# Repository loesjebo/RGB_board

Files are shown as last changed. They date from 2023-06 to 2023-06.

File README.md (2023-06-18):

# RGB_board

Simple 3V board design with tact switch and potmeter to control a RGB LED for a workshop I developed at ArtechLAB Amsterdam for Museum M in Almere. 

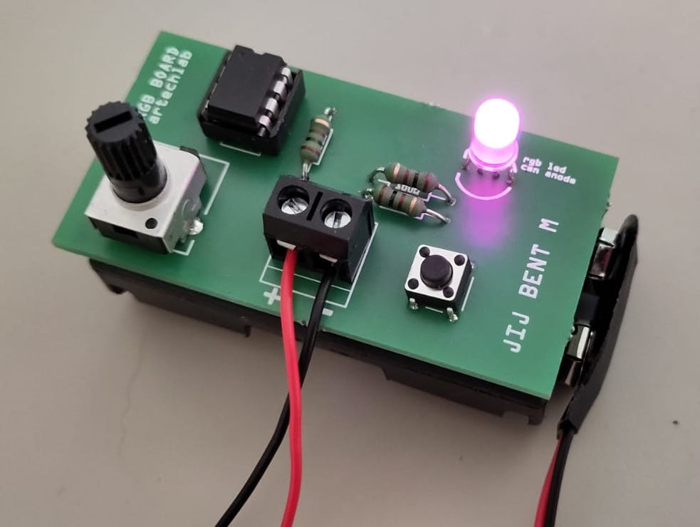
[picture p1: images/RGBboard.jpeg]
bottom of the board
  

## Description

This board runs on 3V and is also the size of a 2x AA battery pack. It features an attiny85 microcontroller, a potentiometer, a tact switch and a common anode RGB LED. 

With the tact switch different color modes can be selected (red, green or blue). Within each color mode, the intensity can be modified by turning the potentiometer knob. 

It was designed for a high school workshop to engage teenagers in immersive designs by playing with lighting and paper structures. 

## Bill of materials

### Tools

**Arduino IDE with following installed**
 
* ATtiny microcontrollers boards (via board manager, see below) 
* The arduino sketch under "files" in this repository [RGB_attiny_pot_switch_3V.ino](./files/RGB_attiny_pot_switch_3V/RGB_attiny_pot_switch_3V.ino) 
* Sparkfun tiny AVR programmer [€22 via robotshop](https://eu.robotshop.com/products/tiny-avr-usb-programmer).

You could also program the ATtiny with an Arduino UNO microcontroller, a breadboard, and a bunch of dupont jumpers. [See this instructable](https://srituhobby.com/how-to-program-attiny85-with-arduino-uno-step-by-step/)

**Hand tools**

* Small flathead screwdriver to connect battery leads to screw terminal
* Soldering iron and solder
* Multimeter

### Components per board

* [Solderable screw terminal (2 ports)](https://www.reichelt.nl/nl/nl/loetbare-schraubklemme-2-pol-rm-5-mm-90--ctb5202-2-p292669.html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)
* [3x 100 ohm resistors](https://www.reichelt.nl/nl/nl/koolstoffilmweerstand-1-4w-5-100-ohm-1-4w-100-p1336.html?&nbc=1)
* [Attiny85 chip (DIP)](https://www.reichelt.nl/nl/nl/8-bit-attiny-avr-risc-microcontroller-8-kb-20-mhz-dip-8-attiny-85-20-pu-p69299.html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)
* [9V battery clip](https://www.reichelt.nl/nl/nl/batterijclip-voor-9-volt-blok-verticaal-clip-9v-p6665.html?&nbc=1)
* [Battery holder 2x AA mignon batteries with connector that matches the battery clip](https://www.reichelt.nl/nl/nl/houder-voor-2-mignoncellen-aa-drukknop-halter-2xum3-dk-p8438.html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)
* [RGB LED (common anode)](https://opencircuit.nl/product/rgb-5mm-diffuse-led-common-anode)
* [Potentiometer ](https://opencircuit.nl/product/10k-rv09-verticale-potentiometer)
* [Tact switch 6 mm](https://opencircuit.nl/product/tactiele-button-6x6x5mm)
* The printed circuit board (PCB) (this design can be ordered [here](https://aisler.net/p/CUOELNLM))
* [2x AA batteries](https://www.reichelt.nl/nl/nl/set-van-40-batterijen-alkaline-mignon-ansmann-ans-al40-pack-p104406.html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)

## Board design

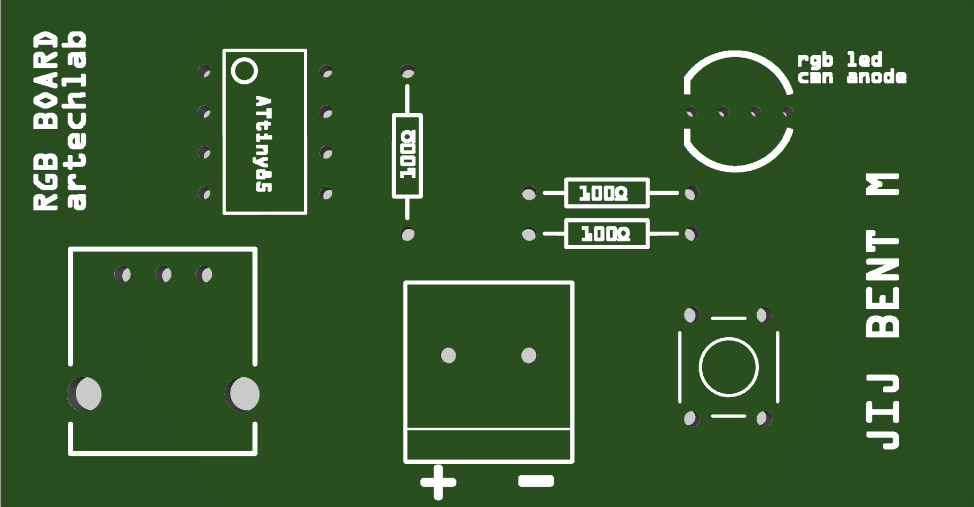
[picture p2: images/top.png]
top of the board
  

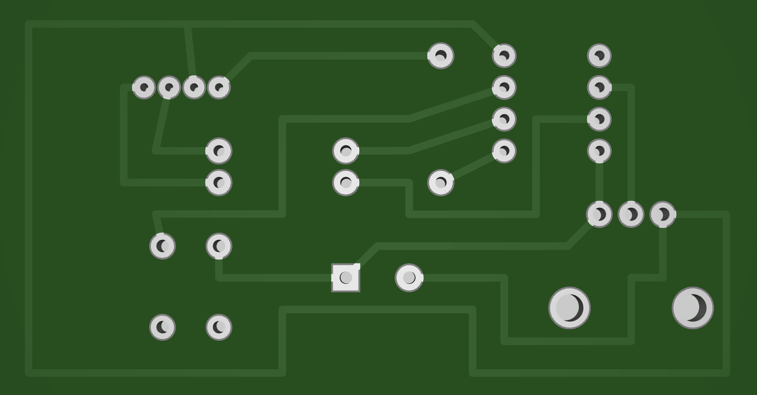
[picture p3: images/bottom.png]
bottom of the board
  

## Programming the ATtiny85 chip

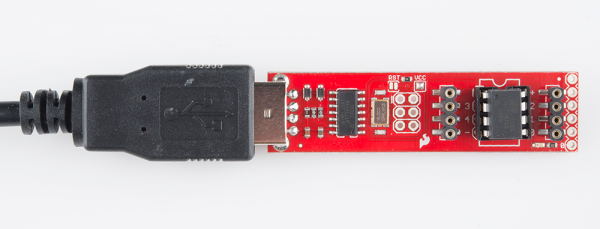
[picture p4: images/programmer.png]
sparkfun tiny avr programmer
  

### Install the [Arduino IDE](https://www.arduino.cc/en/software) software

* Download and open the sketch: [RGB_attiny_pot_switch_3V.ino](./files/RGB_attiny_pot_switch_3V/RGB_attiny_pot_switch_3V.ino)

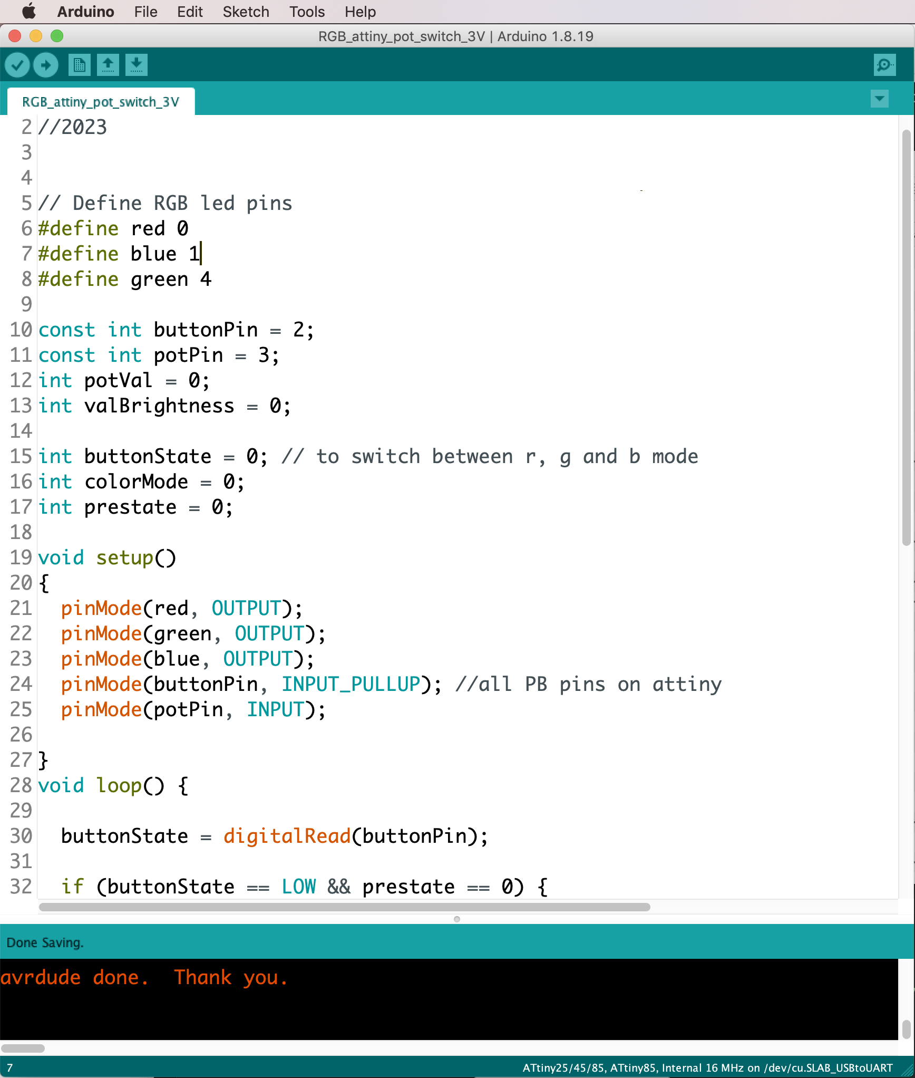
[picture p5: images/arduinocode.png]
	 

### Install the ATtiny board files 

Find via the menu bar *> Tools > Board > Board Manager...*  and search for **"attiny"**. Then click **"install"**.

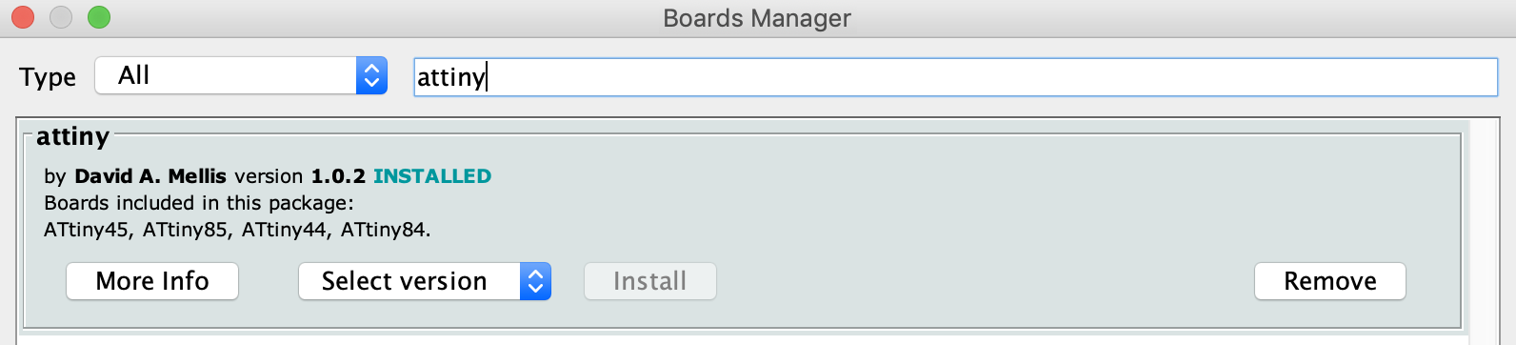
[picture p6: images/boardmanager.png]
 

* Restart the Arduino IDE software and reopen it
* Now you should find **ATtiny microcontrollers** under *Tools > Board*. 

### Selecting the board and programmer

Select **ATtiny25/45/85**

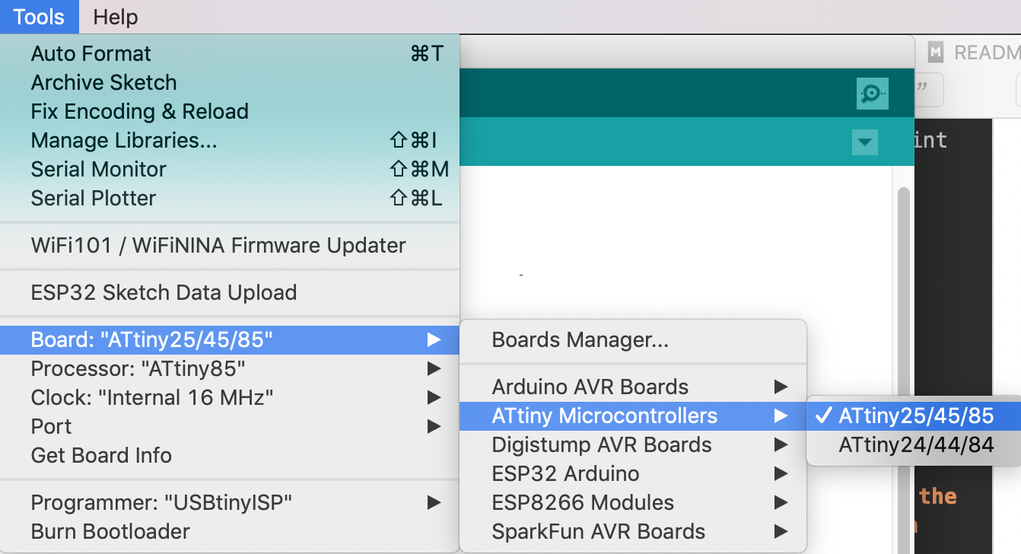
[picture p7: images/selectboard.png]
 

Select the right board settings as in the screenshot

* Board = ATtiny25/45/85
* Processor = ATtiny85
* Clock = Internal 1MHz
* Programmer = USBtinyISP

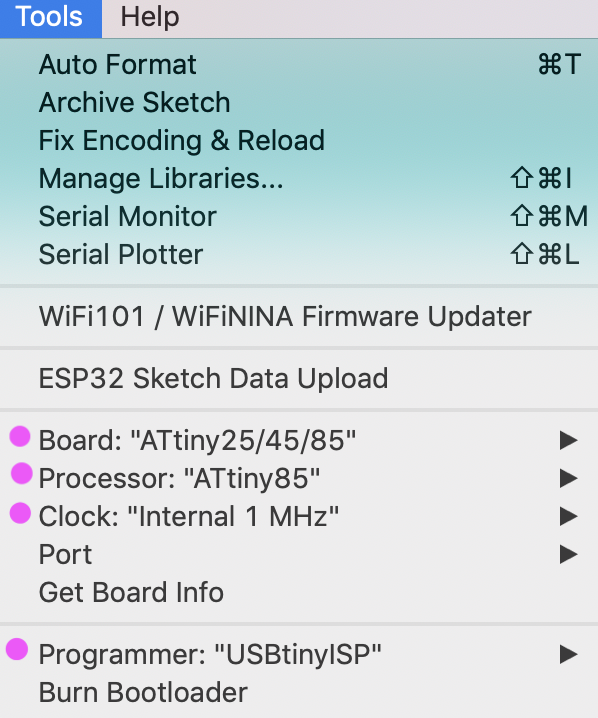
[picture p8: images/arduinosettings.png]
 

### Upload the code via the programmer

* Carefully plug the ATtiny85 chip into the socket on the board. 
	* Make sure the mark on the chip is in the right direction!

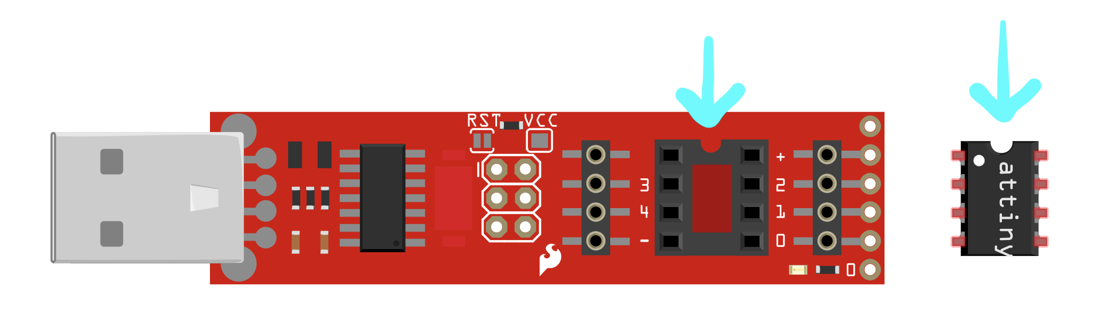
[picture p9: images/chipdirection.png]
	 
	
* Plug the stick into your computer's USB port and select >> **Sketch** >> **Upload** from the menu. The monitor should say "avrdude done. Thank you"

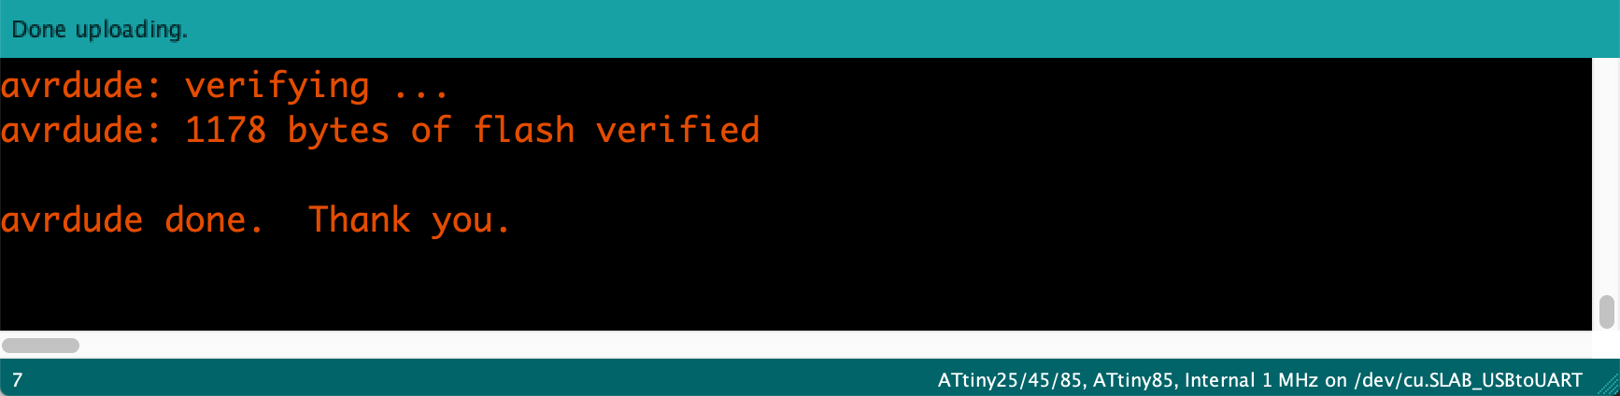
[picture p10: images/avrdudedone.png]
	 

* The Attiny chip has now been programmed

## Assembly

### 1. Program the ATtiny chip before sholdering

See above

### 2. Stuffing the board

Solder all parts to the boards following this diagram. Note the orientation of the following: 

* the long leg on the RGB is the common anode and goes into the second hole of the led footprint
* note the notch on the attiny85 chip, it marks the orientation and should point in the same direction of the little circle in the silkscreen of the footprint
* glue or tie the battery pack to the board, screw the wires into the screw terminal. The red lead goes to the + and the black lead goes to the -. 

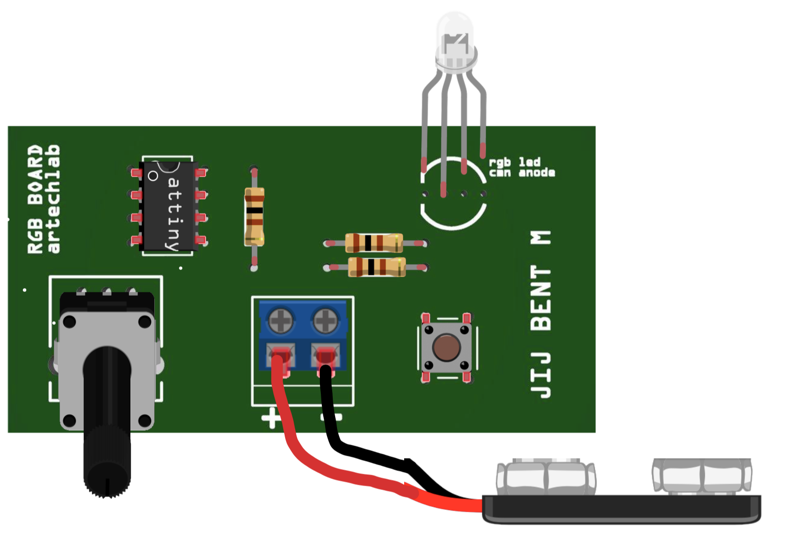
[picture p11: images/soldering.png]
  

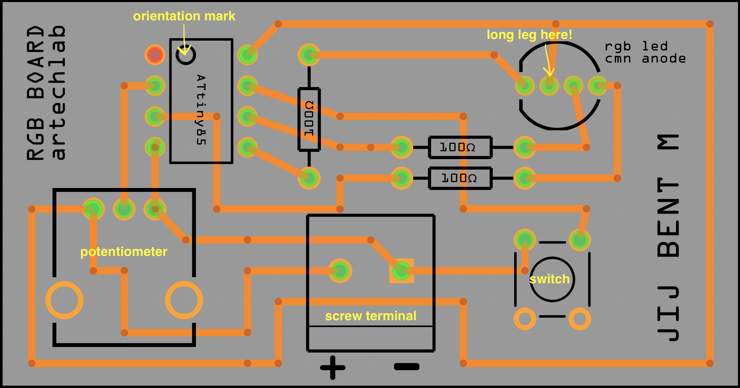
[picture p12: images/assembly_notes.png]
  

### Testing

* I made one board with a 8-pin DIP socket to test the chips without soldering
* Take the chip out and replace with the Attiny we just programmed
* Connect the battery
* Check if everything works (color changes with tshe knob and switch)

[Example video here](./files/test/mp4)

## Disconnect the battery to power off!

**NOTE: To turn off the board: disconnect the battery. Although you can turn off the LED with the potmeter, the chip will continue running and drain the battery. When done: switch it off.s**

## Workshop tutorials

in Dutch only: 

* [Ontwerpinstructies](./files/slides-lichtkunst-workshop.pdf)
* [Docentenhandleiding](./files/docentenhandleiding.pdf)
* [Powerpoint slides](./files/instructiebladen_solderen.pdf)
* [Soldeerinstructies](./files/instructiebladen_vormgeving.pdf)

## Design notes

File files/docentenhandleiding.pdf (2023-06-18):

# Docentenhandleiding lichtkunst workshop

## Gigantische lichtkunstwerken in het klein

Ontwikkeld in opdracht van Museum M in Almere
door Loes Bogers en Meldrid Ibrahim, ArtechLAB Amsterdam, juni 2023

Dompel je onder in de wereld van licht. Tijdens deze workshop ontdekken de leerlingen wat installatiekunst en lichtkunst is. Ze bekijken verschillende kunstwerken waarbij licht als materiaal is gebruikt en de toeschouwer omringd wordt door het kunstwerk. Vervolgens verkennen zij de eigenschappen van licht. Daarna maken zij een eigen lichtkunstwerk op schaal met een lampje wat ze zelf hebben gesoldeerd. De lichtkunstwerken worden tentoongesteld in een verduisterd lokaal.

Doel van de workshop
Na de workshop kan de leerling:
- uitleggen wat installatiekunst is
- verwoorden hoe licht in het dagelijks leven wordt ervaren
- reageren op verschillende voorbeelden van kunstenaars die met licht werken
- verschillende eigenschappen van licht beschrijven
- de eigenschappen van licht creatief toepassen
- een printplaatje solderen
- een levensgrote kunstinstallatie ontwerpen op schaal

Les in stappen

30 min - intro en uitleg

60 min - ronde 1: in duo's aan de slag (solderen/sculpturen)

30 min - pauze

60 min - ronde 2: duo's wisselen van station (solderen/sculpturen)

25 min – installeren en presenteren

5 min - opruimen

Benodigdheden (voor groep van 20 leerlingen)

- Een Padlet account (gratis). Voor de test workshops kan deze gebruikt worden: https://padlet.com/loesbogers1/lichtkunst-workshops-29-30-juni-roovz6whnx5zdnfy
- Vuilniszakken en schilderstape om ramen te verduisteren
- 5x zijkniptangen
- 5x punttang
- 5x soldeerstations (bijv. Weller WE1010)
- 20x stukje loodvrij soldeer, ongeveer 15 cm p/s
- 1 rol desoldeerdraad
- 1x kleine schroevendraaier met platte kop 3 mm
- Rol duct tape om printplaatjes op tafel te plakken bij solderen
- 5x schilderstape, plakband
- 5x hotglue guns en patronen
- Rolletje nylondraad
- 2 grote kartonnen dozen om tijdens werkproces te verduisteren
- 200 gs wit A3 papier, gekleurd cellofaan, kalkpapier, spiegelkarton
- 1x Pritt poster buddies
- 100x Miniatuur figuurtjes schaal 1:50 (Amazon)
- 5x scharen, snijmessen, snijmatten, linealen
- Bonus: vouwbeentjes, ril/snijapparaatjes
- 5-10 werkende, voorgesoldeerde bordjes
- Per groep van 20 leerlingen: 10x elektronica kitje:
- 1x Soldeerbare schroefklem 2-polig
- 3x 100 ohm weerstand (0.25W)
- 1x Attiny85 DIP
- 1x 9V batterij clip
- 1x batterijhouder voor 2 AA cellen
- 2x AA batterij
- 1x RGB led (common anode)
- 1x potmeter
- 1x drukknop 6 mm
- 1x custom printplaatje

## Voorbereiding

- Lees deze handleiding goed door en klik door de powerpoint
- Maak zelf de opdracht en noteer de vragen die leerlingen zouden kunnen hebben
- Op locatie: verduister het lokaal met tape en vuilniszakken
- Op locatie: dek evt sensor af (zodat het licht niet aangaat)
- Richt werkstations in:

Station solderen
- Bij open raam: 5 soldeerstations, per stations 2 stoelen (totaal 10)
- Per station: instructieblad, zijkniptang, soldeer, soldeerstation, onderdelen, PCB op tafel vast te zetten met tape of pritt poster buddies

Station vormgeven
- Tafels in eilandjes: 5 tafels met elk 2 stoelen (totaal 10)
- Knutselmaterialen: papier, scharen, tape, snijmatten enz
- Kartonnen dozen om installatie tijdelijk te verduisteren
- 5x gesoldeerde lampjes
- Poster buddies, miniatuurmensjes
- Inspiratiematerialen: voorbeeldjes en geprinte instructiebladen

# | Deel 1 - Intro en uitleg – 30 min

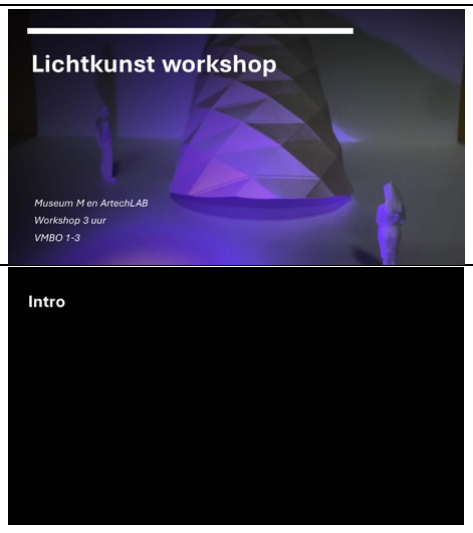
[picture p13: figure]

1 Opening | Open de workshop. Stel jezelf voor en vertel wat de leerlingen gaan doen: een gezamenlijke expositie van lichtkunstwerken maken. Hoe precies, dat leg je later uit. Vertel dat jullie eerst gaan nadenken over licht. Hoe belangrijk is licht eigenlijk in ons dagelijks leven?
2 Intro-oefening – 5 min | Het lokaal is vooraf donker gemaakt. De workshopleiders pakken een lampje en kijken samen met de leerlingen wat het effect is om deze vanaf verschillende posities op iemand te schijnen. De leerlingen geven de instructies. Daarna richten ze zich op de ruimte, wat gebeurt er als de lamp er steeds vanaf een ander standpunt op schijnt?

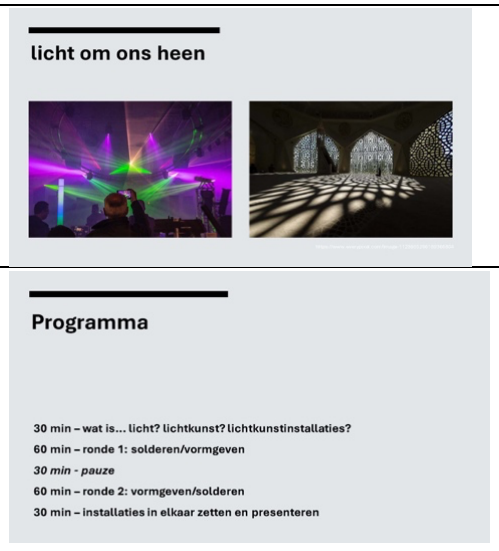
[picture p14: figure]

3 Dagelijks leven | Bespreek met de leerlingen dat licht en ruimte altijd om ons heen is. Dat de manier waarop licht de ruimte binnenvalt veel invloed heeft. Kennen de leerlingen voorbeelden uit het dagelijks leven?
4 Programma | • Vandaag dompelen we ons onder in de wereld van licht door lichtkunst installaties te maken. • We bekijken samen een aantal voorbeelden en denken na over licht. Daarna gaan jullie zelf aan de slag. • We beginnen bij het begin, wat is lichtkunst eigenlijk? (volgende slide)

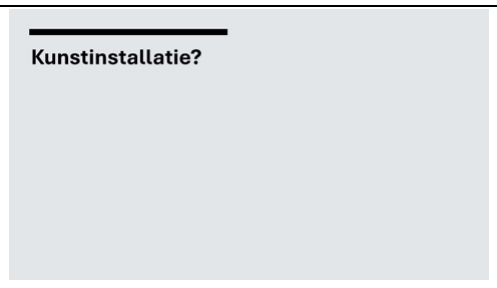
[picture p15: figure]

5 Kunst-installaties met licht | Wie heeft er wel eens een kunstinstallatie gezien? Kan iemand uitleggen hoe een "installatie" anders is dan bijvoorbeeld een schilderij aan de muur? Een kunstinstallatie ervaar je met je hele lichaam, en vaak met meerdere zintuigen. Je kunt er omheen lopen en van verschillende kanten bekijken, of beter nog: misschien kun je er zelfs in kruipen, er onderdoor lopen, erin verdwalen. Als bezoeker ben je als het ware "in" het kunstwerk. Een aantal voorbeelden....

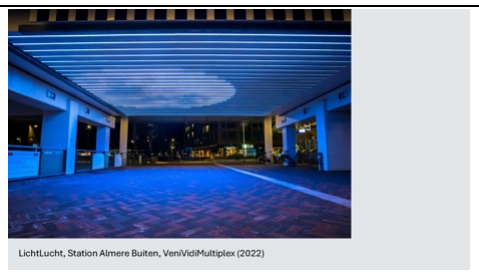
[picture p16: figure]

6 Kunstwerk: LichtLucht, Station Almere Buiten | Dit is een lichtkunstwerk in Almere Buiten. Heeft iemand het wel eens gezien? Je kunt er onderdoor fietsen of lopen en het is onderdeel van de stad. Zou je ook onder dit kunstwerk gaan liggen om even weg te dromen? Waarom wel/niet? https://arttenders.com/projects/lichtlucht-lichtinstallatie/
7 Kunstwerk: The Weather Project van Olafur Eliasson | Dit kunstwerk is een enorme zon die geplaatst is in een klassieke museumzaal. De mensen op de foto staan ernaar te kijken, maar er zijn ook veel foto's van mensen die uren in de hal liggen de mijmeren in het "zonlicht".
8 Kunstwerk: Your Uncertain Shadow van Olafur Eliasson | Dit werk is juist activerend, verschillende kleuren lampjes geven een regenboog aan schaduwen. Door de opstelling in de ruimte nodigt het uit om zelf schaduwen te maken met je lijf, door voor de lampen te bewegen en dansen.
9 Kunstwerk: Waterlicht van Daan Roosegaarde | Dit kunstwerk op het Museumplein in Amsterdam wil juist aandacht vragen voor een serieuze kwestie. Het licht boven de hoofden van de mensen laat zien hoe hoog de zeespiegel in de toekomst zal komen te staan.
10 Opdracht | Jullie uitdaging voor vandaag is om zo'n gigantische lichtkunsinstallatie te ontwerpen. We maken het in het klein en gebruiken miniatuur figuurtjes om te verbeelden hoe het er op ware grootte uit zou zien.
11 Verkennen: Hoe gedraagt licht zich? Hoe reageert het | met andere materialen? Wat weet je al over licht? Kun je iets noemen? Met het lampje kan de docent deze eigenschappen demonstreren, om het visueel te maken zodat leerlingen het makkelijker kunnen benoemen.

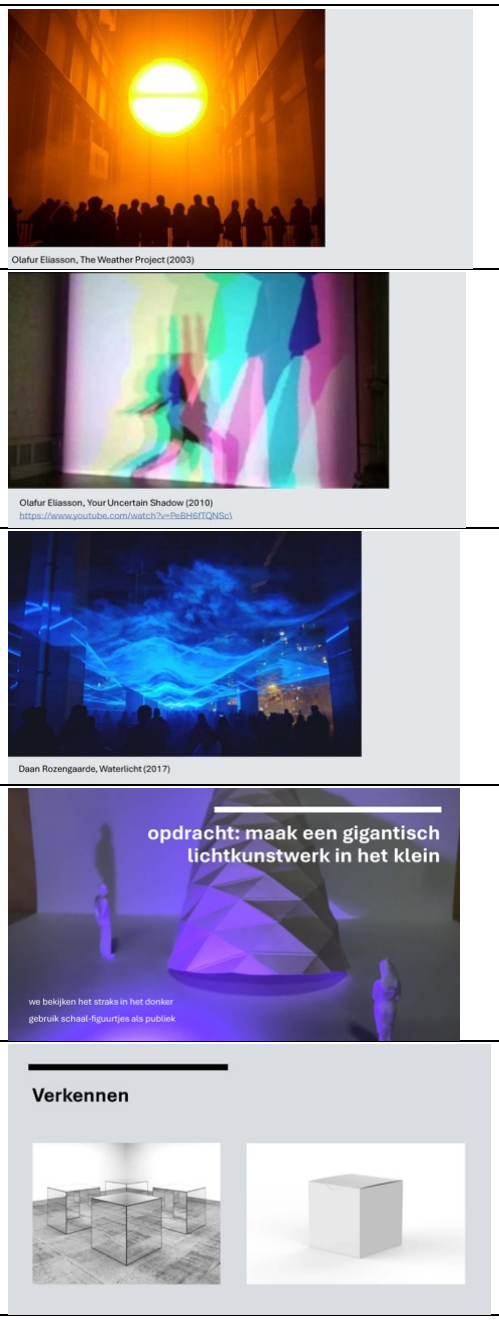
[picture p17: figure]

| • Als licht wordt geblokkeerd krijg je schaduwen • Licht kan diffuus zijn (zachte schaduw) of direct, dan krijg je een scherpe slagschaduw • Licht verplaatst zich in rechte lijnen en kan gereflecteerd worden (bijv spiegels) • Wit licht bestaat uit alle kleuren samen • Je kunt afzonderlijke kleuren er ook uit filteren • Oppervlakken kunnen helemaal transparant zijn (bijv. een raam), iets lichtdoorlatend (bijv. kalkpapier), reflecterend (bijv. een spiegel) of het licht blokkeren (bijv. karton)

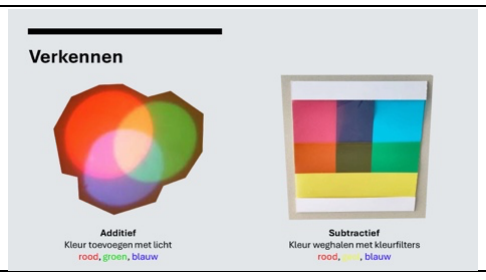
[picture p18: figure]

12 Verkennen: licht en kleur | Met kleur werken in een lichtkunstwerk kan op twee manieren: door te mengen (additief), of te filteren (subtractief). We geven je straks beide opties om mee te experimenteren
13 Spelregels | • Jullie gaan nu aan je eigen lichtkunstwerk werken • Daarvoor mogen jullie kleurlampjes solderen, en een kunstinstallatie ontwerpen. • Er is een soldeerstation en een ontwerpstation en hebt voor beide onderdelen een uur. • Na de pauze wissel je van station. • Aan het eind bekijken we elkaars werk. Maak tweetallen en kies een station om mee te beginnen (solderen of vormgeven). Na de pauze wissel je van station. Vraag de groep tweetallen te maken (bijv. werk met je buur) en zich te verdelen over de stations.
| Deel 2 Ronde 1 – 60 min

## Station solderen

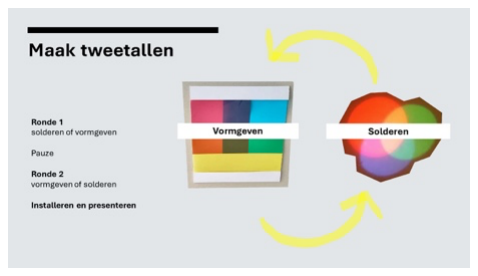
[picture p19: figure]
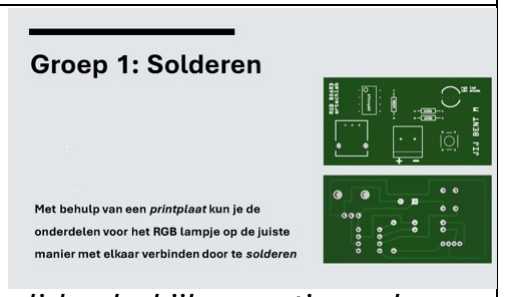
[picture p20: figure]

14 > 1 setje per soldeerstation (nog geen batterijen geven) | Zorg dat er een ca. 5 bordjes voorgesoldeerd zijn, en er een paar reserve zijn, voor het geval er bordjes of onderdelen kapotgaan in de les. Leg uit: met behulp van een printplaat kun je de onderdelen voor het lampje op de juiste manier verbinden door te solderen | slides bekijken optioneel

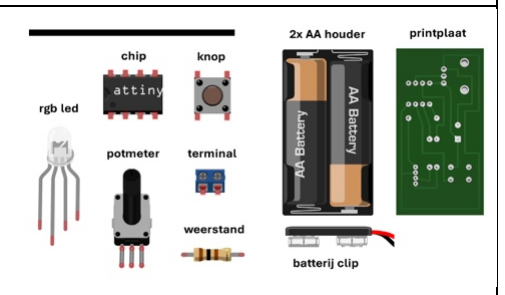
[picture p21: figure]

15 Onderdelen | De begeleider bij het soldeerstation benoemt de verschillende onderdelen en wijst ze aan. Zeg erbij: de batterij krijg je op het laatst, als je klaar bent (Zo kan de workshopdocent controleren op fouten en evt corrigeren, dit verkleint het risico op beschadigde bordjes)

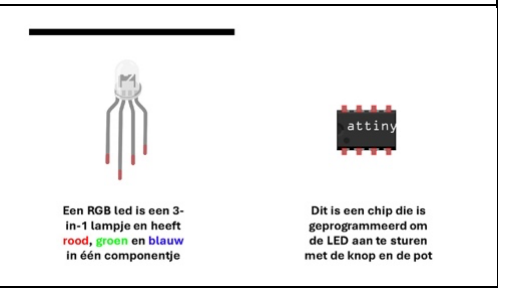
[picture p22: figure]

16 Hoe werken de RGB Led en de chip? | Een RGB led is een 3-in-1 lampje en heeft rood, groen en blauw in een onderdeeltje. Je kunt daarmee dus mengen met kleuren. Je moet het wel aansturen, dat doen we met een chip die geprogrammeerd is om de LED te besturen met de knop en de potentiometer (de draaiknop).

17 Soldeerbasics: elementen | Wijs deze onderdelen aan op tafel: Soldeer, componenten, printplaat, soldeerijzer.

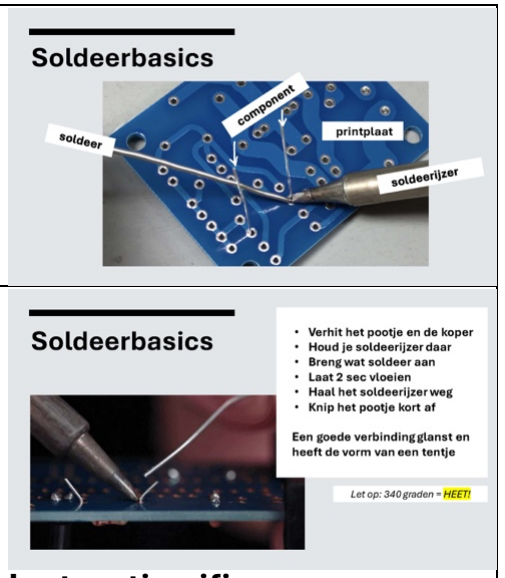
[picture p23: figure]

18 Soldeerbasics: proces | Laat de GIF zien op je computerscherm Leg de stappen uit en wijs aan wanneer je ze ziet gebeuren in de GIF. VEILIGHEID: • Afspraken om veilig te werken: • Het soldeerijzer is extreem heet, werk geconcentreerd • Ga rustig zitten en laat je niet afleiden • Vraag partner om een handje waar nodig • Zet onderdeeltjes/bordje vast met tape/poster buddies • We zitten bij het raam zodat de gassen weg kunnen uit het lokaal | Instructie gifje: https://thumbs.gfycat.com/S andySinfulBullfrog-size_restricted.gif

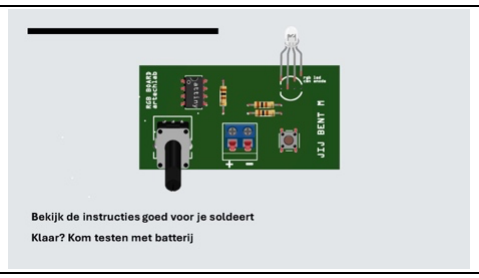
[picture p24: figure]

19 Aan de slag! | • Deel instructiebladen voor solderen uit. • Vraag leerlingen de instructies goed te bekijken en om hulp te vragen waar nodig. • Geef aan dat ze kunnen komen testen met een batterij als ze klaar zijn.

Als leerling klaar is, check dan eerst het bordje op soldeerfouten, met name:

- Richting van de RGB LED en de chip
- Zijn er geen pootjes per ongelijk aan elkaar gesoldeerd waar dat niet moet?
- Zit de rode draad van de batterij clip in de + van de schroefterminal?

Tip voor workshopleiders: als er een foutje is gemaakt kun je het onderdeel loshalen door eerst het soldeer te verwijderen met een kopervlechtje. Zie deze gif:

https://thumbs.gfycat.com/GloriousPaltryFish-size_restricted.gif

Daarna kun je het onderdeel verwijderen. Als het pootje nog vastzit evt. overgebleven soldeer nog een keer verhitten en terwijl het warm is verwijderen.

## Station vormgeving

Zorg dat materialen en instructiebladen op tafels liggen. In het plenaire deel heeft de docent een korte demo gegeven van de materialen om kenmerken van licht te laten zien.

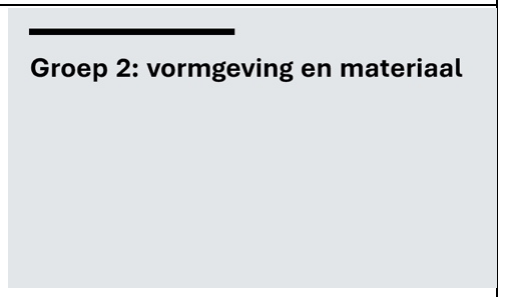
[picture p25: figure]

20 (Slides bekijken = optioneel) | Veiligheidsafspraken • Niet lopen met messen en scharen • Gebruik een lineaal bij het snijden, houd je vingers weg uit de snijrichting (doe dit voor) • Hotglue guns zijn heet, let op je vingers • Werk geconcentreerd, laat je niet afleiden

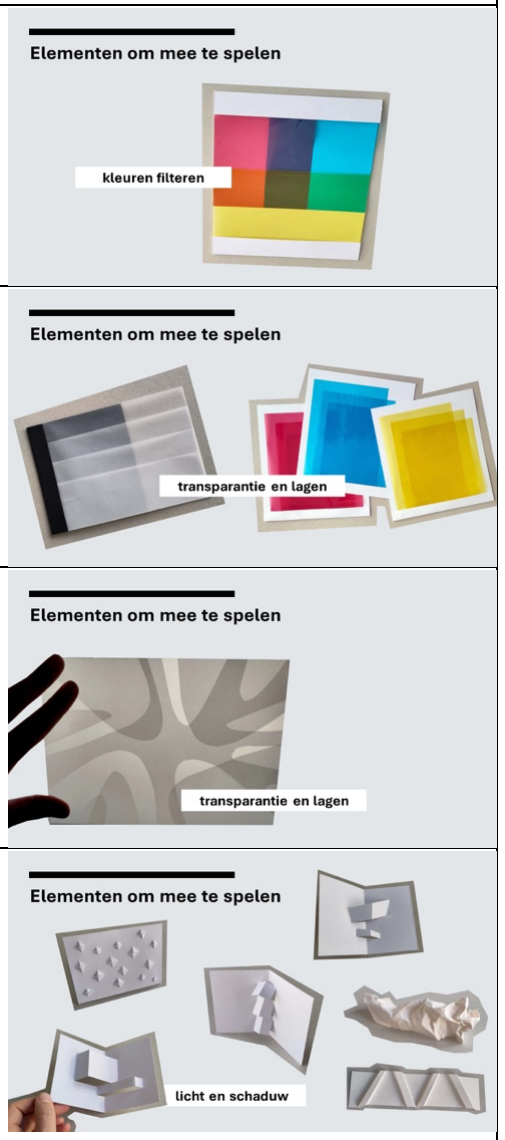
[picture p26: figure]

21 Elementen om mee te spelen | Met kleurenfilters van gekleurd cellofaan kun je spelen met kleur. Met een rood filter, een geel filter, en een blauw filter maak je oranje, groen, paars en bruin/zwart
22 Elementen om mee te spelen | Kalkpapier en cellofaan zijn niet 100% transparant, door lagen op te bouwen maak je kalkpapier lichter/witter, en het cellofaan donkerder/dieper van kleur
23 Elementen om mee te spelen | Je kunt hiermee ook spelen in vrije vorm
24 Elementen om mee te spelen | Speel met licht en schaduw door verschillende technieken uit te proberen: • Maak textuur door te vouwen, knippen, snijden, scheuren, of het papier op te frommelen • Je kunt ook constructies maken door onderdelen te knippen/snijden, vouwen en aan elkaar te lijmen.

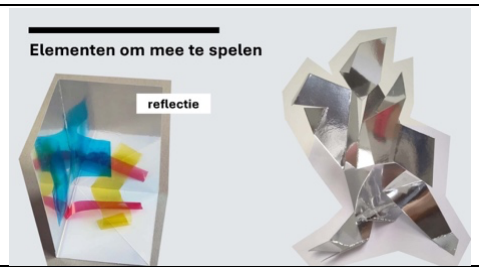
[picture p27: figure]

25 Elementen om mee te spelen | Met spiegelkarton en spiegelfolie kun je spelen met weerkaatsingen/reflectie

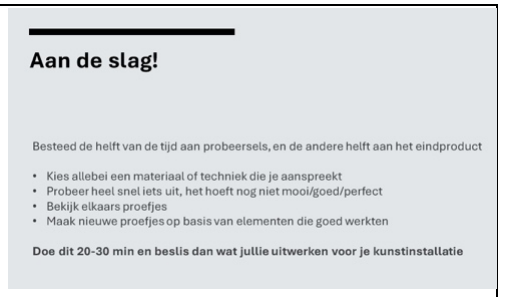
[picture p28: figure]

26 Aan de slag! | Tip: besteed de helft van de tijd aan probeersels, en de andere helft aan het eindproduct. • Kies allebei een materiaal of techniek uit die je aanspreekt • Probeer heel snel iets uit, het hoeft nog niet mooi/goed/perfect • Bekijk elkaars proefjes • Maak nieuwe proefjes op basis van elementen die goed werkten Doe dit 20-30 min en beslis dan wat jullie uitwerken voor je kunstinstallatie Workshopleiders lopen rond en geven waar nodig begeleiding en stellen vragen. Probeer leerlingen uit te dagen om hun proefjes meteen ruimtelijk te maken.

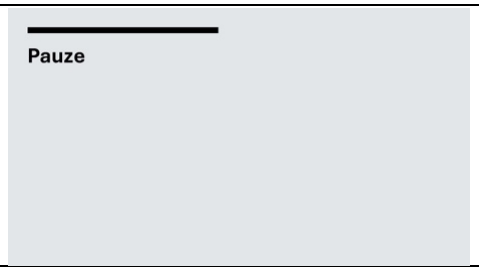
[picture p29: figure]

| Pauze We hebben 15 min pauze, dan wisselen
| Deel 3 Ronde 2 – 60 min
| Heb je gesoldeerd? Dan ga je nu vormgeven. Heb je al een installatie vormgegeven? Dan ga je nu solderen. Over 60 min moeten beide onderdelen af zijn.

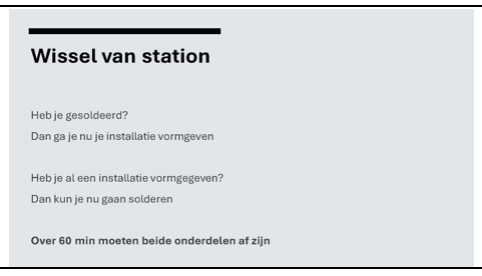
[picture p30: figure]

| Deel 4 Installeren en presenteren – 30 min

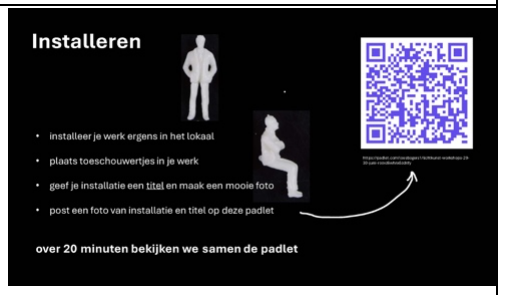
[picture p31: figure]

| Licht de laatste stappen toe: • installeer je werk ergens in het lokaal • plaats toeschouwertjes in je werk • geef je installatie een titel en maak een foto van je werk • post een foto van installatie en titel op deze padlet: https://padlet.com/loesbogers1/lichtkunst-workshops-29-30-juni-roovz6whnx5zdnfy De leerlingen maken hun kunstwerk gereed voor de expo. De workshopdocenten maken het lokaal weser donker.

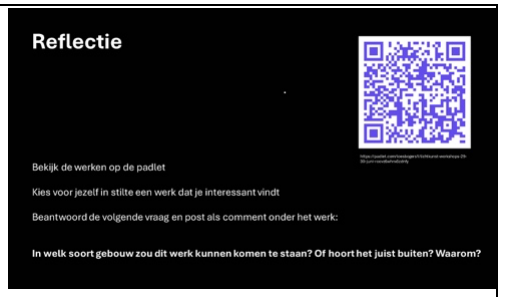
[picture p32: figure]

Reflectie oefening • Bekijk de werken op de padlet en kies voor jezelf in stilte een werk dat je interessant vindt • Beantwoord de volgende vraag en post als comment onder het werk: In welk soort gebouw zou dit werk kunnen komen te staan? Of hoort het juist buiten? Waarom?

Bedank de leerlingen + opruimen Leerlingen kunnen lampjes meenemen maar per duo max. 1 meegeven anders kom je tekort in workshop 2. Organiseer de stations en leg nieuwe materialen klaar

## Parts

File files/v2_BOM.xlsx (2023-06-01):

3V RGB kit met potmeter en knop
Onderdelen per kit | €6.44 | wordt goedkoper bij grotere aantallen
Soldeerbare schroefklem 2-polig | €0.22 | https://www.reichelt.nl/nl/nl/loetbare-schraubklemme-2-pol-rm-5-mm-90--ctb5202-2-p292669.html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
100 ohm weerstand x3 | €0.30 | https://www.reichelt.nl/nl/nl/metaaloxide-weerstand-2w-5-100-ohm-2w-metall-100-p2312.html?trstct=pol_0&nbc=1
Attiny85 DIP | €2.14 | https://www.reichelt.nl/nl/nl/8-bit-attiny-avr-risc-microcontroller-8-kb-20-mhz-dip-8-attiny-85-20-pu-p69299.html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
9V batterij clip | €0.24 | https://www.reichelt.nl/nl/nl/batterijclip-voor-9-volt-blok-verticaal-clip-9v-p6665.html?&nbc=1
Batterijhouder 2x AA | €0.37 | https://www.reichelt.nl/nl/nl/houder-voor-2-mignoncellen-aa-drukknop-halter-2xum3-dk-p8438.html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
batterijen 2x | €0.25 | https://www.reichelt.nl/nl/nl/set-van-40-batterijen-alkaline-mignon-ansmann-ans-al40-pack-p104406.html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
RGB led common anode | €0.24 | https://opencircuit.nl/product/rgb-5mm-diffuse-led-common-anode
potmeter | €0.51 | https://opencircuit.nl/product/10k-rv09-verticale-potentiometer
Tact switch 12mm | €0.10 | https://opencircuit.nl/product/tactiele-button-6x6x5mm
PCB board | €2.07 | https://aisler.net/p/CUOELNLM
Overige en verzendkosten
IC test clip SOIC 8-pin x2 | €9.00 | https://opencircuit.nl/product/ic-test-clip-soic-8-pin
Verzendkosten Reichelt | €6.95
Verzendkosten OpenCircuit | €3.50
Besteld
Reichelt | €63.64 | incl post
Aisler | €31.01 | incl post
OpenCircuit | €27.40 | incl post
TOTAAL | €122.05 | >>> 10 weggeven, 5 zelf houden past in budget

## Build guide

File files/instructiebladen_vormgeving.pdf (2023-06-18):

# Groep 2: vormgeving en materiaal

## Elementen om mee te spelen

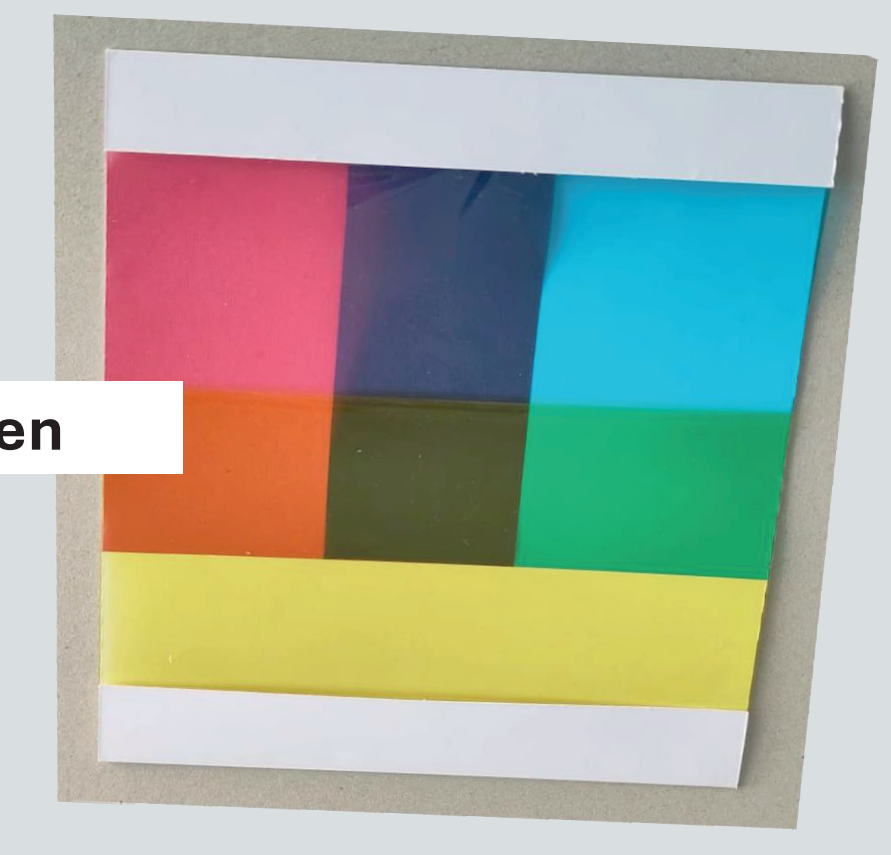
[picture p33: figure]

kleuren filteren

Besteed de helft van de tijd aan probeersels, en de andere helft aan het eindproduct

- Kies allebei een materiaal of techniek die je aanspreekt
- Probeer heel snel iets uit, het hoeft nog niet mooi/goed/perfect
- Bekijk elkaars proefjes
- Maak nieuwe proefjes op basis van elementen die goed werkten

Doe dit 20-30 min en beslis dan wat jullie uitwerken voor je kunstinstallatie

## Elementen om mee te spelen

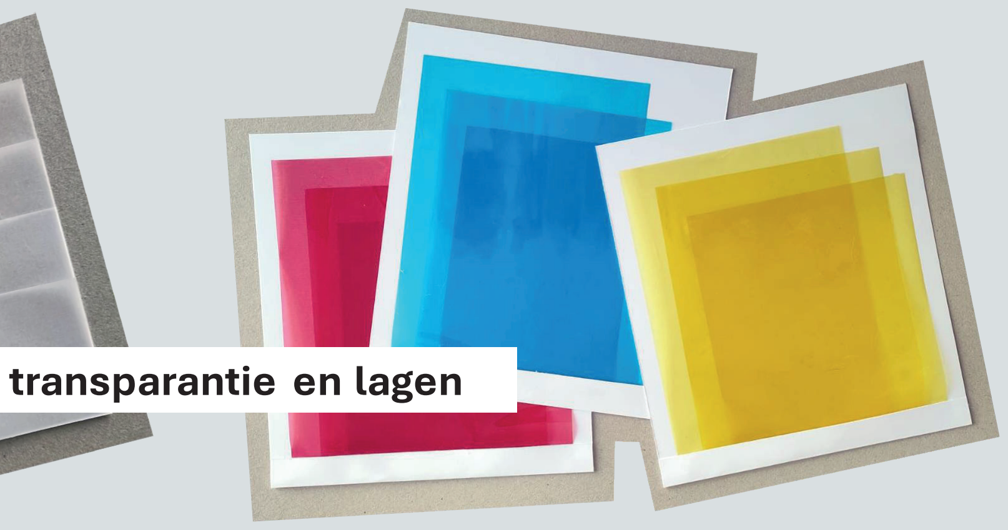
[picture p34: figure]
transparantie en lagen
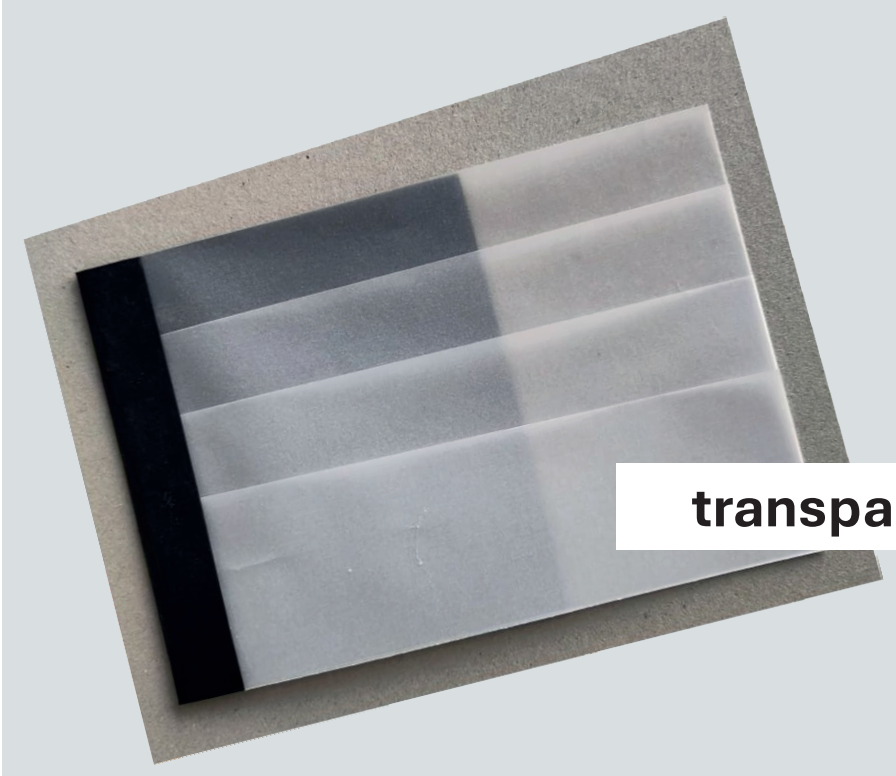
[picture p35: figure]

## Elementen om mee te spelen

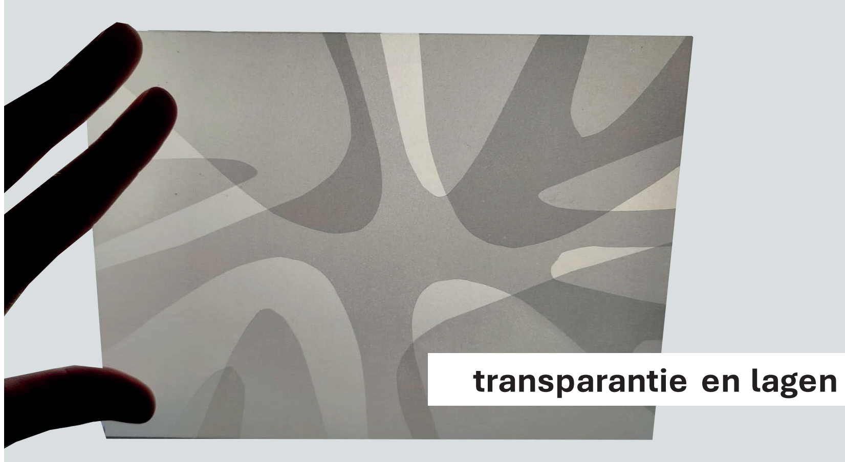
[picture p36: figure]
transparantie en lagen

## Elementen om mee te spelen

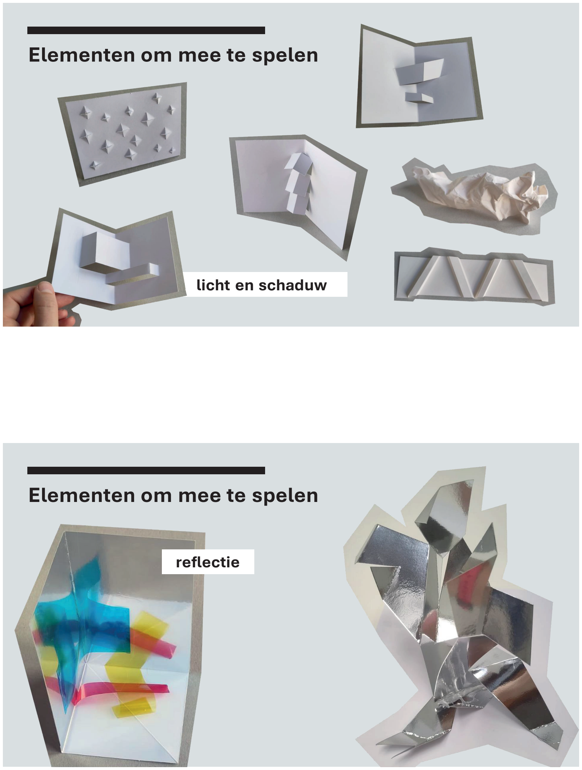
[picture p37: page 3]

licht en schaduw

## Elementen om mee te spelen

reflectie

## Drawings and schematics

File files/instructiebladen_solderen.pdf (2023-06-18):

# Soldeerbasics

Let op: 340 graden = HEET!

- Verhit het pootje en de koper
- Houd je soldeerijzer daar
- Breng wat soldeer aan
- Laat 2 sec vloeien
- Haal het soldeerijzer weg

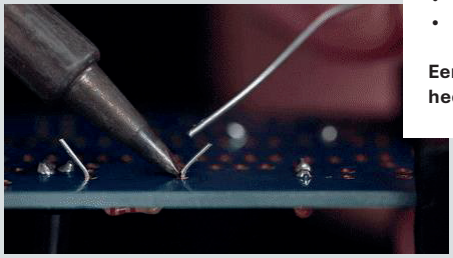
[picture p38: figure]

- Knip het pootje kort af

Een goede verbinding glanst en heeft de vorm van een tentje

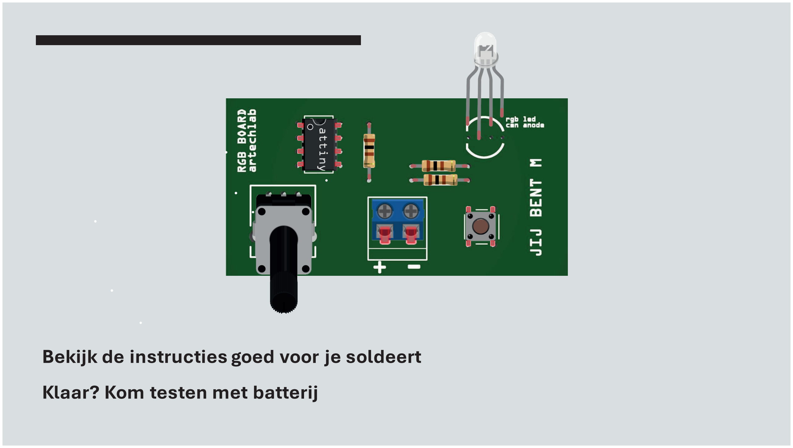
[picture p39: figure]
Klaar? Kom testen met batterij

Bekijk de instructies goed voor je soldeert

# Stap 1

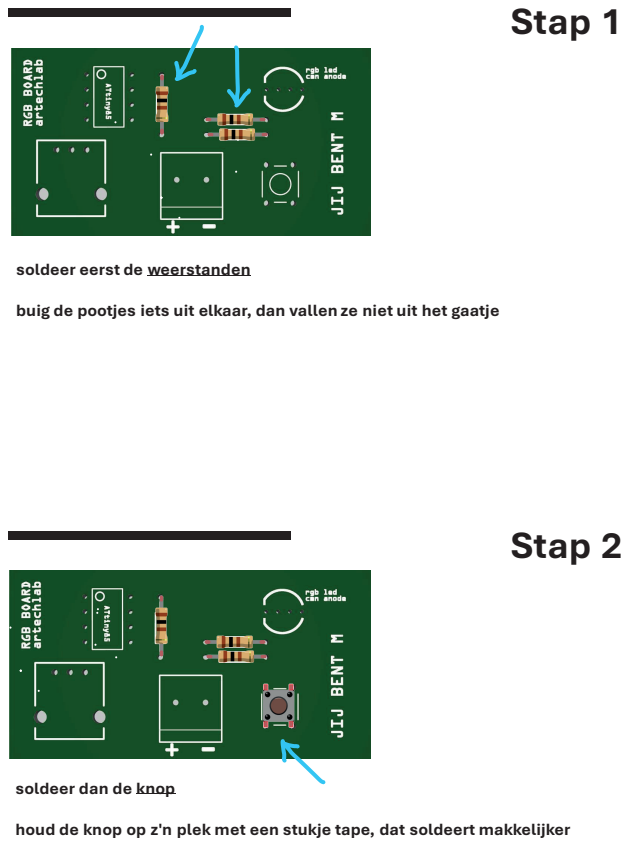
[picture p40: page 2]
Stap 2

soldeer eerst de weerstanden

buig de pootjes iets uit elkaar, dan vallen ze niet uit het gaatje

soldeer dan de knop

houd de knop op z'n plek met een stukje tape, dat soldeert makkelijker

# Stap 3

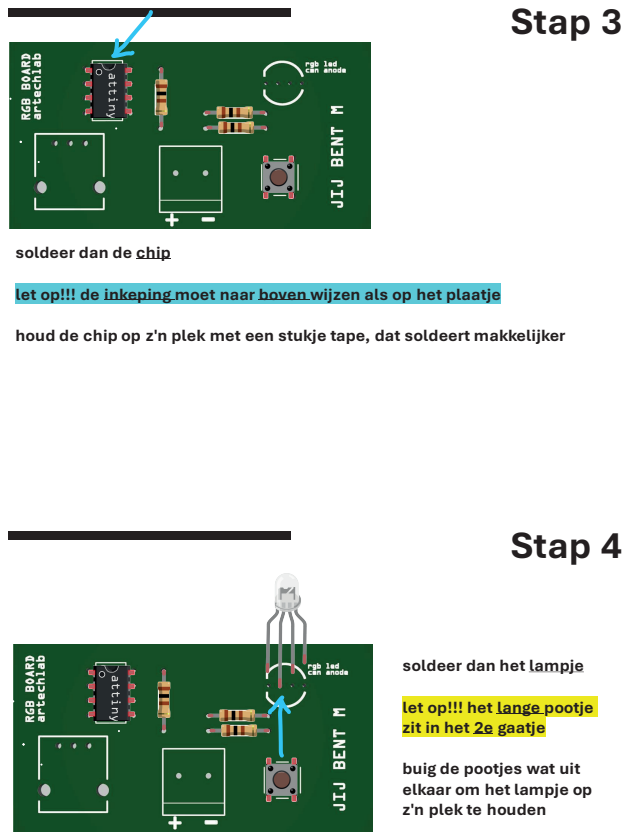
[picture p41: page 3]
Stap 4

soldeer dan de chip

let op!!! de inkeping moet naar boven wijzen als op het plaatje

houd de chip op z'n plek met een stukje tape, dat soldeert makkelijker

soldeer dan het lampje

let op!!! het lange pootje
zit in het 2e gaatje

buig de pootjes wat uit
elkaar om het lampje op
z'n plek te houden

# Stap 5

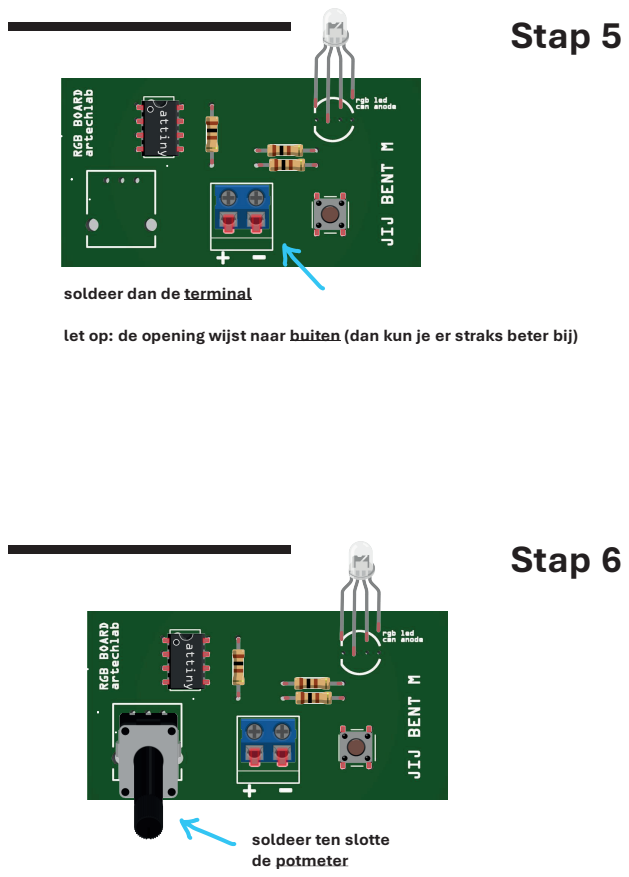
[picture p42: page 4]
Stap 6

soldeer dan de terminal

let op: de opening wijst naar buiten (dan kun je er straks beter bij)

soldeer ten slotte
de potmeter

# Stap 7

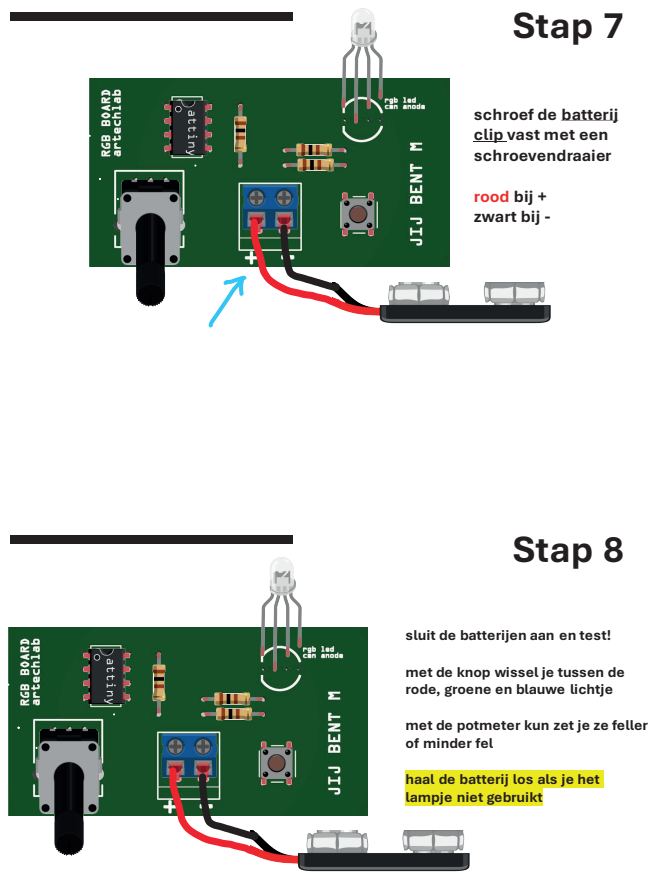
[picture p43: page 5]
rood bij + zwart bij -; Stap 8

schroef de batterij
clip vast met een
schroevendraaier

sluit de batterijen aan en test!

met de knop wissel je tussen de
rode, groene en blauwe lichtje

met de potmeter kun zet je ze feller
of minder fel

haal de batterij los als je het
lampje niet gebruikt

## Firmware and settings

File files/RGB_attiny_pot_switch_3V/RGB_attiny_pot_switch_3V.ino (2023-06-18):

//Loes Bogers - ArtechLAB
//2023


// Define RGB led pins
#define red 0
#define blue 1 
#define green 4

const int buttonPin = 2;
const int potPin = 3;
int potVal = 0;
int valBrightness = 0;

int buttonState = 0; // to switch between r, g and b mode
int colorMode = 0;
int prestate = 0;

void setup()
{
  pinMode(red, OUTPUT);
  pinMode(green, OUTPUT);
  pinMode(blue, OUTPUT);
  pinMode(buttonPin, INPUT_PULLUP); //all PB pins on attiny
  pinMode(potPin, INPUT);

}
void loop() {

  buttonState = digitalRead(buttonPin);

  if (buttonState == LOW && prestate == 0) {
    colorMode++;

    if (colorMode > 2) {
      colorMode = 0;
    }
    prestate = 1;
  } else if (buttonState == HIGH) {
    prestate = 0;
  }

  potVal = analogRead(potPin);
  int mode = colorMode;    //mode 0 = R, 1 = G, 2 = B
  valBrightness = map(potVal, 0, 1023, 255, 0); //map pot values with inversion bcs RGB has common anode

  switch (mode) {
    case 0:
      analogWrite(red, valBrightness);
      break;
    case 1:
      analogWrite(blue, valBrightness);
      break;
    case 2:
      analogWrite(green, valBrightness);
      break;
  }
}
